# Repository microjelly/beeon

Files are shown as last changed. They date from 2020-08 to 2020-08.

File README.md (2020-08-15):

# beeon

## Overview
The classic device was created several years ago to fill a single need, preventing my work computer from auto locking due to inactivity. *Subverting security policy comes with a responsibility to ensure that you lock your computer (CTRL+ALT+DEL) everytime you walk away!*  

## classic notes
### flash bootloader to board
`avrdude -c USBasp -p attiny85 -U flash:w:beeon-classic-v1-micronucleus-2.04.hex:i -B 10`  
`avrdude -c USBasp -p attiny85 -U lfuse:w:0xe1:m -U hfuse:w:0xdd:m -U efuse:w:0xfe:m`  
### upload new firmware onto board
`micronucleus --run {firmware.hex}`
### clear out any existing firmware
`micronucleus --erase-only`
### upload firmware with random serial number
*first create random serial number file*  
`beeon-classic-sn -mk -mk-p=Z-ZZ > beeon-sn.txt`  
`beeon-classic-sn | micronucleus --run -`

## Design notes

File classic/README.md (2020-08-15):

[finished-product-image]: hw/img/classic-v1.jpg "BEEON - Classic; v1"
[pcb-top-image]: hw/img/classic-v1-top.png "BEEON - Classic; v1; pcb-top"
[pcb-bottom-image]: hw/img/classic-v1-bottom.png "BEEON - Classic; v1; pcb-bottom"

# classic hardware

## Overview
The classic device was created several years ago to fill a single need, preventing my work computer from auto locking due to inactivity. *Subverting security policy comes with a responsibility to ensure that you lock your computer (CTRL+ALT+DEL) everytime you walk away!*  

Alternatively the device can also be used as a low-pin USB development platform, by soldering a pin header to the exposed pads on the bottom you can access 3 GPIOS, VCC (3v3+), GND and the RESET pin of the ATTINY85. Making it a very low-pin count development board with USB capabilities.

---
## Firmware
The firmware makes use of the outstanding V-USB software-only implementation of low-speed USB devices. If you plan on making changes or releasing your own devices please change the vendor/device names as well as the vendor/product ids within the [usbconfig.h](fw/v1/usbconfig.h) file.
    
`V-USB` is released under the [GPLv2](https://github.com/obdev/v-usb/blob/master/usbdrv/License.txt) license.

---
## Bootloader
Micronucleus is the bootloader that is currently in use by the beeon-classic devices. You will need a copy of the commandline tool for your operating system inorder to upload new firmware onto the device. v2.04 is the version that we are currently using.
  
| OS | Link |
| -- | -- |
| Windows | [Download](https://github.com/micronucleus/micronucleus/raw/master/commandline/micronucleus.exe) |
| Linux/Darwin | [Build](https://github.com/micronucleus/micronucleus/tree/master/commandline) |
`Micronucleus` is released under the [GPLv2](https://github.com/micronucleus/micronucleus/blob/master/License.txt) license.

---
## BOM
| Reference(s) | Package  | Description | Manufacturer | Part Number | **Cost |
| --- | ---: | --- | --- | ---: | -----: |
| SW1 | | Switch | E-Switch | *TL1014BF180QG | $#.##  |
| D1 | 1206 | LED | OSRAM Opto | *LG N971-KN-1 | $#.##  |
| J1 | | 6 PIN 2.54mm (Optional Header) | Harwin | M20-7820646 | $0.95  |
| J2 | | USB | CNC-Tech | 1001-011-01101 | $0.77  |
| R1 | 0805 | 47 Ohm Resistor | Vishay/Dale | CRCW080547R0FKEA | $0.10  |
| R2 | 0805 | 1K5 Ohm Resistor | Vishay/Dale | CRCW08051K50FKEB | $0.17  |
| R3 | 0805 | 68 Ohm Resistor | Vishay/Dale | CRCW080568R0FKEA | $0.10  |
| R4 | 0805 | 68 Ohm Resistor | Vishay/Dale | CRCW080568R0FKEA | $0.10  |
| U1 | SOIC-8 | ATtiny85 MCU | Atmel | ATtiny85-20SU | $1.13  |
| U2 | SOT-23-5 | 1 00mA 3.3 LDO | Texas Instruments | TPS79133DBVR | $1.32  |
| C1 | 1206 | 10uF 10v Tantalum Capacitor | AVX | F931A106KAA | $0.49  |
| C2 | 1206 | 0.1uF 10v MLCC Capacitor | Vishay/Vitramon | VJ1206Y104KXQPW1BC | $0.29  |
| C3 | 1206 | 0.01uF 10v MLCC Capacitor | Vishay/Vitramon | VJ1206Y103KXJCW1BC | $0.25  |
| C4 | 1206 | 1uF 16v Tantalum Capacitor | AVX | F931C105KAA | $0.51  |

**obsolete part (need to find replacement)*  
***cost last updated on 8/14/2020*

---
## PCB
[`Order from OSH Park`](https://oshpark.com/shared_projects/amtuUCdw)  
               

---
## Finished Product
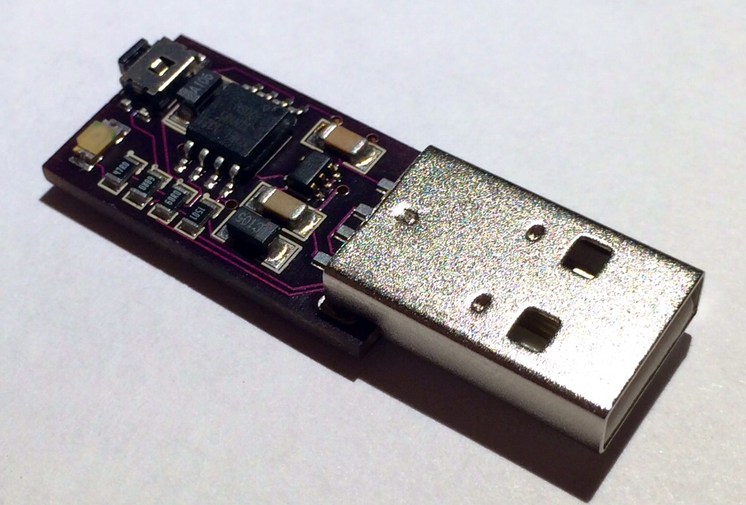
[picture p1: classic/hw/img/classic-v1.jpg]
|  |
| :---------------------------------- |

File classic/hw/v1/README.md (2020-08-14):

[finished-product-image]: classic-v1.jpg "BEEON - Classic; v1"
[pcb-top-image]: classic-v1-top.png "BEEON - Classic; v1; pcb-top"
[pcb-bottom-image]: classic-v1-bottom.png "BEEON - Classic; v1; pcb-bottom"

# classic v1 hardware
## Overview
A brief overview of why have a classic version

## BOM
Some words aboutthe current bom
| Reference(s) | Package  | Description | Manufacturer | Part Number | Cost  |
| --- | --- | --- | --- | --- | ----- |
| SW1 | | Switch | E-Switch | *TL1014BF180QG | $#.## |
| D1 | 1206 | LED | OSRAM Opto | *LG N971-KN-1 | $#.## |
| J1 | | 6 PIN 2.54mm (Optional Header) | Harwin | M20-7820646 | $0.95 |
| J2 | | USB | CNC-Tech | 1001-011-01101 | $0.77 |
| R1 | 0805 | 47 Ohm Resistor | Vishay/Dale | CRCW080547R0FKEA | $0.10 |
| R2 | 0805 | 1K5 Ohm Resistor | Vishay/Dale | CRCW08051K50FKEB | $0.17 |
| R3 | 0805 | 68 Ohm Resistor | Vishay/Dale | CRCW080568R0FKEA | $0.10 |
| R4 | 0805 | 68 Ohm Resistor | Vishay/Dale | CRCW080568R0FKEA | $0.10 |
| U1 | SOIC-8 | ATtiny85 MCU | Atmel | ATtiny85-20SU | $1.13 |
| U2 | SOT-23-5 | 1 00mA 3.3 LDO | Texas Instruments | TPS79133DBVR | $1.32 |
| C1 | 1206 | 10uF 10v Tantalum Capacitor | AVX | F931A106KAA | $0.49 |
| C2 | 1206 | 0.1uF 10v MLCC Capacitor | Vishay/Vitramon | VJ1206Y104KXQPW1BC | $0.29 |
| C3 | 1206 | 0.01uF 10v MLCC Capacitor | Vishay/Vitramon | VJ1206Y103KXJCW1BC | $0.25 |
| C4 | 1206 | 1uF 16v Tantalum Capacitor | AVX | F931C105KAA | $0.51 |

*obsolete part (need to find replacement)

## PCB
Some quick words abou the pcb [`Order from OSH Park`](https://oshpark.com/shared_projects/amtuUCdw)
|   | 
| -------------------------------------------------------- |

## Finished Product
Some quick words about the finished product
|  |
| :---------------------------------- |

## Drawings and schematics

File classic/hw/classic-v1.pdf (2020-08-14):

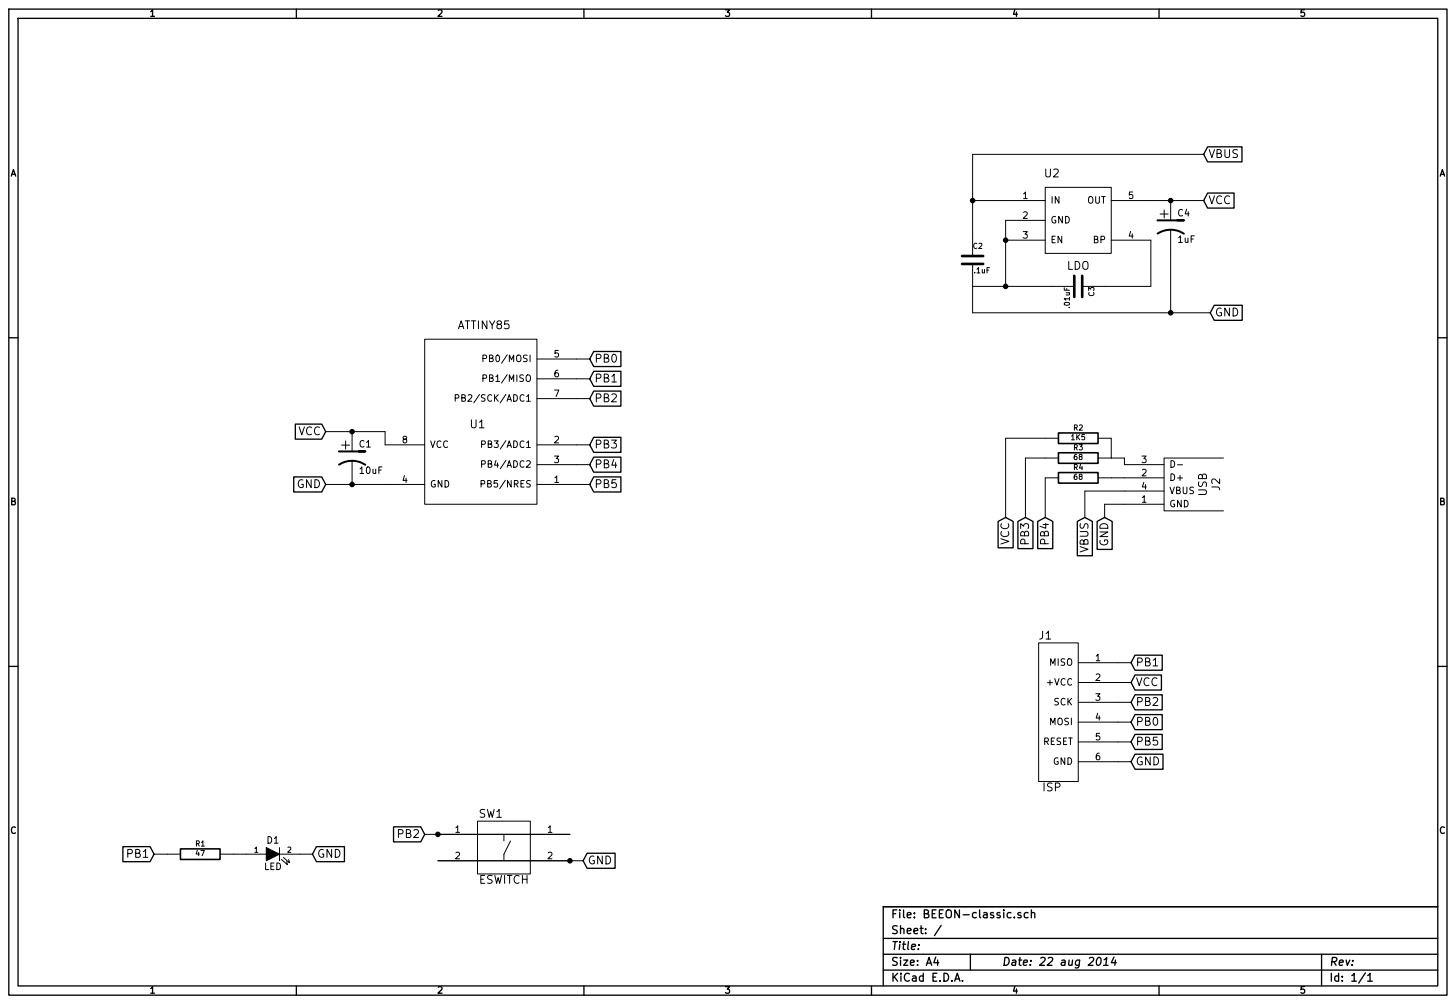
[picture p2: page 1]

Id: 1/1 Title: File: BEEON-classic.sch
Sheet: /

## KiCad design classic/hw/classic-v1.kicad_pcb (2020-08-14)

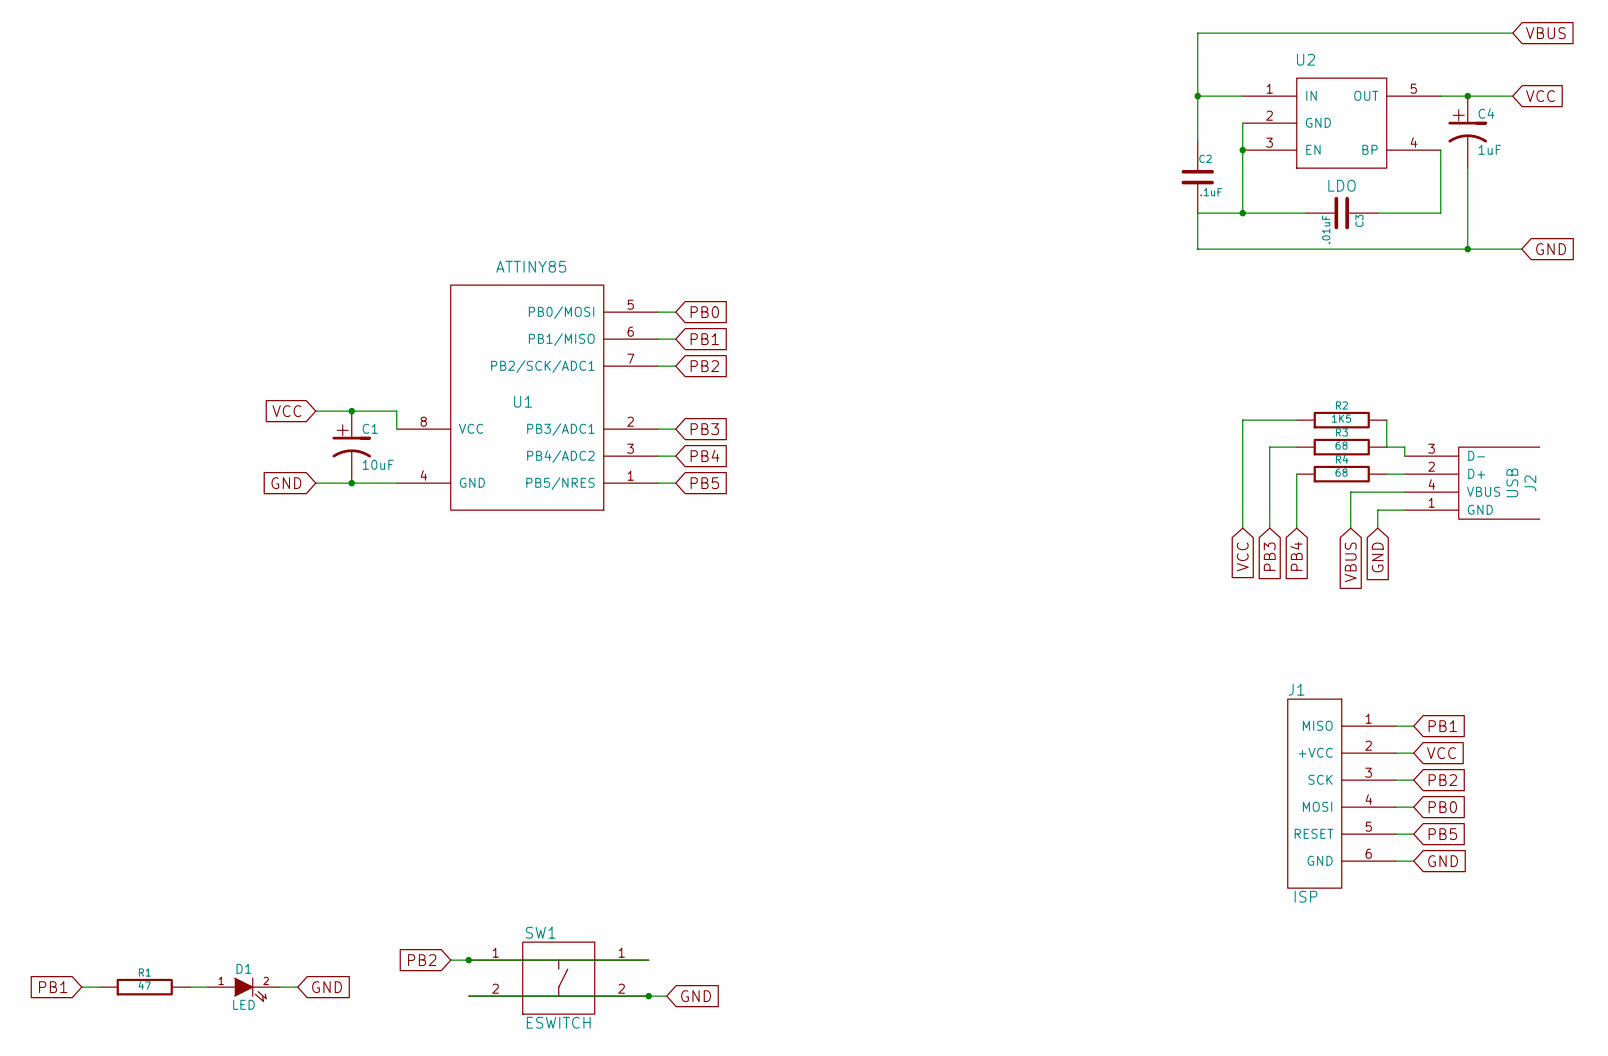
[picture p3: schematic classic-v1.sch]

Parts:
C1: 10uF
C2: .1uF
C3: .01uF
C4: 1uF
D1: LED
J1: ISP
J2: USB
R1: 47
R2: 1K5
R3, R4: 68
SW1: ESWITCH
U1: ATTINY85
U2: LDO

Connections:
GND: C1.2, C2.2, C3.2, C4.2, D1.2 (K), J1.6 (GND), J2.1 (GND), SW1.2, U1.4 (GND), U2.2 (GND), U2.3 (EN)
unnamed: J2.3 (D-), R2.2, R3.2
unnamed: J2.2 (D+), R4.2
unnamed: D1.1 (A), R1.2
unnamed: C3.1, U2.4 (BP)
PB0: J1.4 (MOSI), U1.5 (PB0/MOSI)
PB1: J1.1 (MISO), R1.1, U1.6 (PB1/MISO)
PB2: J1.3 (SCK), SW1.1, U1.7 (PB2/SCK/ADC1)
PB3: R3.1, U1.2 (PB3/ADC1)
PB4: R4.1, U1.3 (PB4/ADC2)
PB5: J1.5 (RESET), U1.1 (PB5/NRES)
VBUS: C2.1, J2.4 (VBUS), U2.1 (IN)
VCC: C1.1, C4.1, J1.2 (+VCC), R2.1, U1.8 (VCC), U2.5 (OUT)

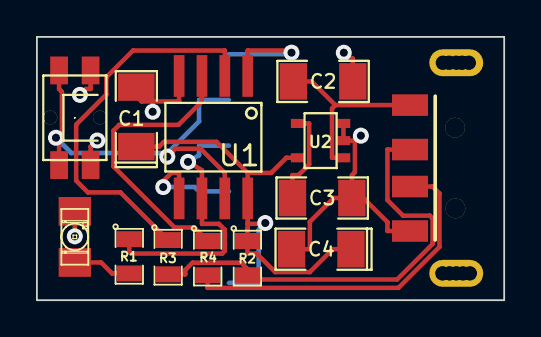
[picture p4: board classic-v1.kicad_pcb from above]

Board: 2 copper layers, 26.0 x 14.6 mm, 14 parts (1 on the bottom side), 13 nets.

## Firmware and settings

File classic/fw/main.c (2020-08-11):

#include <avr/io.h>
#include <avr/wdt.h>
#include <avr/eeprom.h>
#include <avr/interrupt.h>  /* for sei() */
#include <util/delay.h>     /* for _delay_ms() */
#include <stdlib.h>

#include <avr/pgmspace.h>   /* required by usbdrv.h */
#include "usbdrv.h"

#define BIT_KEY 2
#define BIT_LED 1

#define EEPROM_OSC	0
#define EEPROM_DM   1
#define EEPROM_DR	2
#define EEPROM_KK	3
#define EEPROM_MM	4

#define MOUSE_B     1
#define MOUSE_X     2
#define MOUSE_Y     3
#define MOUSE_W	    4

#define DS_IDLE     10
#define DS_ACTIVE   20

#define DR_FAST     1
#define DR_NORMAL   8
#define DR_SLOW     16
#define DR_EXSLOW   32

#define DM_MOUSE    10
#define DM_KEYBOARD 20

#define MM_CIRCLE   10
#define MM_RANDOM   20

#define LED_MAX		9

#define FR_DS		1
#define FR_DM		2
#define FR_DR		3
#define FR_KK		4
#define FR_MM		5

#define KK_0	    0x27
#define KK_CAPS     0x39
#define KK_DEFAULT	KK_0

/* ------------------------------------------------------------------------- */
/* ----------------------------- USB interface ----------------------------- */
/* ------------------------------------------------------------------------- */

PROGMEM const char usbHidReportDescriptor[USB_CFG_HID_REPORT_DESCRIPTOR_LENGTH] = {

// Mouse 
//	-------------------------------------------------------------------------
	0x05, 0x01,//	Usage Page (Generic Desktop),							|
	0x09, 0x02,//	Usage (Mouse),											|
	0xA1, 0x01,//	Collection (Application),								|
	0x09, 0x01,//		Usage (Pointer)										|
	0xA1, 0x00,//		Collection (Physical),								|
//	-------------------------------------------------------------------------
	0x85, 0x01,//			Report Id (1).									|
//	-------------------------------------------------------------------------
	0x05, 0x09,//			Usage Page (Buttons),							|
	0x19, 0x01,//			Usage Minimum (01),								|
	0x29, 0x03,//			Usage Maximun (03),								|
	0x15, 0x00,//			Logical Minimum (0),							|
	0x25, 0x01,//			Logical Maximum (1),							|
	0x95, 0x03,//			Report Count (3),								|
	0x75, 0x01,//			Report Size (1),								|
	0x81, 0x02,//			Input (Data, Var, Abs),							|
	0x95, 0x01,//			Report Count (1),								|
	0x75, 0x05,//			Report Size (5),								|
	0x81, 0x03,//			Input (Constant), ;5 bit padding				|
//	-------------------------------------------------------------------------
	0x05, 0x01,//			Usage Page (Generic Desktop),					|
	0x09, 0x30,//			Usage (X),										|
	0x09, 0x31,//			Usage (Y),										|
	0x09, 0x38,//			Usage (Wheel),									|
	0x15, 0x81,//			Logical Minimum (-127),							|
	0x25, 0x7F,//			Logical Maximum (127),							|
	0x75, 0x08,//			Report Size (8),								|
	0x95, 0x03,//			Report Count (3),								|
	0x81, 0x06,//			Input (Data, Var, Rel)							|
//	-------------------------------------------------------------------------
	0xC0,//				End Collection,										|
//	-------------------------------------------------------------------------
// Configuration interface
//	-------------------------------------------------------------------------
	0x09, 0x00,//	    USAGE (Vendor Usage 1)								|
//	-------------------------------------------------------------------------
	0x85, 0x03,//		Report Id (3)										|
//	-------------------------------------------------------------------------
	0x15, 0x00,//		LOGICAL_MINIMUM (0)									|
	0x26, 0xff, 0x00,//	LOGICAL_MAXIMUM (255)								|
	0x75, 0x08,//		REPORT_SIZE (8)										|
	0x95, 0x05,//		REPORT_COUNT (5)									|
	0xb1, 0x02,//		FEATURE (Data,Var,Abs)								|
	0xC0,//			End Collection											|
//	-------------------------------------------------------------------------

// Keyboard
//	-------------------------------------------------------------------------
	0x05, 0x01,//	USAGE_PAGE (Generic Desktop)							|
	0x09, 0x06,//	USAGE (Keyboard)										|
	0xa1, 0x01,//	COLLECTION (Application)								|
//	-------------------------------------------------------------------------
	0x85, 0x02,//		Report Id (2)										|
//	-------------------------------------------------------------------------
	0x05, 0x07,//		USAGE_PAGE (Keyboard)								|
	0x19, 0xe0,//		USAGE_MINIMUM (Keyboard LeftControl)				|
	0x29, 0xe7,//		USAGE_MAXIMUM (Keyboard Right GUI)					|
	0x15, 0x00,//		LOGICAL_MINIMUM (0)									|
	0x25, 0x01,//		LOGICAL_MAXIMUM (1)									|
	0x75, 0x01,//		REPORT_SIZE (1)										|
	0x95, 0x08,//		REPORT_COUNT (8)									|
	0x81, 0x02,//		INPUT (Data,Var,Abs)								|
//	-------------------------------------------------------------------------
	0x95, 0x05,//		REPORT_COUNT (5)									|
	0x75, 0x01,//		REPORT_SIZE (1)										|
	0x05, 0x08,//		USAGE_PAGE (LEDs)									|
	0x19, 0x01,//		USAGE_MINIMUM (Num Lock)							|
	0x29, 0x05,//		USAGE_MAXIMUM (Kana)								|
	0x91, 0x02,//		OUTPUT (Data,Var,Abs)								|
//	-------------------------------------------------------------------------
	0x95, 0x01,//		REPORT_COUNT (1)									|
	0x75, 0x03,//		REPORT_SIZE (3)										|
	0x91, 0x03,//		OUTPUT (Cnst,Var,Abs)								|
//	-------------------------------------------------------------------------
	0x95, 0x06,//		REPORT_COUNT (6)									|
	0x75, 0x08,//		REPORT_SIZE (8)										|
	0x15, 0x00,//		LOGICAL_MINIMUM (0)									|
	0x25, 0x65,//		LOGICAL_MAXIMUM (101)								|
	0x05, 0x07,//		USAGE_PAGE (Keyboard)								|
	0x19, 0x00,//		USAGE_MINIMUM (Reserved (no event indicated))		|
	0x29, 0x65,//		USAGE_MAXIMUM (Keyboard Application)				|
	0x81, 0x00,//		INPUT (Data,Ary,Abs)								|
//	-------------------------------------------------------------------------
	0xc0,//			END_COLLECTION  										|
//	-------------------------------------------------------------------------
};



static uchar currentAddress;
static uchar bytesRemaining;

static uchar mouseReportBuffer[5]    = { 1, 0,0,0,0 };
static uchar keyboardReportBuffer[8] = { 2, 0,0,0,0,0,0,0 };
static uchar featureReportBuffer[6]  = { 3, 0,0,0,0,0 };

static int   	sinus = 7 << 6, cosinus = 0;
static uchar    idleRate;   /* repeat rate for keyboards, never used for mice */

static uchar 	deviceStatus = DS_IDLE;
static uchar	deviceRate   = DR_NORMAL;
static uchar	deviceMode   = DM_MOUSE;
static uchar	mouseMode    = MM_RANDOM;
static uchar	keyboardKey  = KK_DEFAULT;
static uchar    runToken     = 1; 

static void toggleDeviceStatus()
{
    if(deviceStatus==DS_ACTIVE){

        deviceStatus = DS_IDLE;
        PORTB |= 1 << BIT_LED;      /* LED on */
    }else{
    
        deviceStatus = DS_ACTIVE;
        PORTB &= ~(1 << BIT_LED);   /* LED off */
    }
}


static void keyPoll(void)
{
static uchar    keyMirror;
uchar           key;

    key = PINB & (1 << BIT_KEY);
    if(keyMirror != key){   /* status changed */
        keyMirror = key;
        if(!key) toggleDeviceStatus();
    }
}

static void timerPoll(void)
{
static int timerCnt;
static int timerCnt2;
static int timerLed;

    if(TIFR & (1 << TOV1)){
        TIFR = (1 << TOV1); /* clear overflow */
        keyPoll();
        if(++timerCnt >= deviceRate){
          timerCnt = 0;
          if(++timerCnt2 >= deviceRate){
            timerCnt2 = 0;
            runToken = 1;
          }
        }
        if(++timerLed >= LED_MAX){
            timerLed = 0;
            if(deviceStatus==DS_ACTIVE && (PINB & (1 << BIT_KEY)) ){
              PORTB &= ~(1 << BIT_LED);   /* LED off */
            }
        }
    }
}

/* The following function advances sin/cos by a fixed angle
 * and stores the difference to the previous coordinates in the report
 * descriptor.
 * The algorithm is the simulation of a second order differential equation.
 */
static void advanceCircleByFixedAngle(void)
{
char    d;

#define DIVIDE_BY_64(val)  (val + (val > 0 ? 32 : -32)) >> 6    /* rounding divide */

    mouseReportBuffer[MOUSE_X] = d = DIVIDE_BY_64(cosinus);
    sinus += d;
    mouseReportBuffer[MOUSE_Y] = d = DIVIDE_BY_64(sinus);
    cosinus -= d;
}

static void randomMouse(void)
{

    mouseReportBuffer[MOUSE_X] = ((rand() / (RAND_MAX / 254 + 1))-128)/8;
    mouseReportBuffer[MOUSE_Y] = ((rand() / (RAND_MAX / 254 + 1))-128)/8;
}

/* ------------------------------------------------------------------------- */

/* usbFunctionWrite() is called when the host sends a chunk of data to the
 * device. For more information see the documentation in usbdrv/usbdrv.h.
 */
uchar usbFunctionWrite(uchar *data, uchar len) {

	uchar i;
	
    if(bytesRemaining == 0)
        return 1;               /* end of transfer */
    if(len > bytesRemaining)
        len = bytesRemaining;

	for(i = 0; i < len; i++) {

		if(currentAddress==FR_DS && data[i]!=0xff && data[i]!=deviceStatus) toggleDeviceStatus();
		else if(currentAddress==FR_DM && data[i]!=0xff && data[i]!=deviceMode && (data[i]==DM_MOUSE||data[i]==DM_KEYBOARD) ) {
			eeprom_write_byte(EEPROM_DM, data[i]);
			deviceMode=data[i];
		} else if(currentAddress==FR_DR && data[i]!=0xff && data[i]!=deviceRate) {
			eeprom_write_byte(EEPROM_DR, data[i]);
			deviceRate=data[i];
		} else if(currentAddress==FR_KK && data[i]!=0xff && data[i]!=keyboardKey) {
			eeprom_write_byte(EEPROM_KK, data[i]);
			keyboardKey=data[i];
		} else if(currentAddress==FR_MM && data[i]!=0xff && data[i]!=mouseMode && (data[i]==MM_CIRCLE||data[i]==MM_RANDOM) ) {
			eeprom_write_byte(EEPROM_MM, data[i]);
			mouseMode=data[i];
		}

    	currentAddress++;
    }
      
    currentAddress += len;
    bytesRemaining -= len;
    return bytesRemaining == 0; /* return 1 if this was the last chunk */
}

usbMsgLen_t usbFunctionSetup(uchar data[8])
{
usbRequest_t    *rq = (void *)data;

    /* The following requests are never used. But since they are required by
     * the specification, we implement them in this example.
     */
    if((rq->bmRequestType & USBRQ_TYPE_MASK) == USBRQ_TYPE_CLASS){    /* class request type */
        if(rq->bRequest == USBRQ_HID_GET_REPORT){
            /* wValue: ReportType (highbyte), ReportID (lowbyte) */
            if (rq->wValue.bytes[0] == 1) {
                usbMsgPtr = (void *)&mouseReportBuffer;
                return sizeof(mouseReportBuffer);
            } else if (rq->wValue.bytes[0] == 2) {
                usbMsgPtr = (void *)&keyboardReportBuffer;
                return sizeof(keyboardReportBuffer);
            } else if (rq->wValue.bytes[0] == 3) {
            	featureReportBuffer[FR_DS] = deviceStatus;
            	featureReportBuffer[FR_DM] = deviceMode;
            	featureReportBuffer[FR_DR] = deviceRate;
            	featureReportBuffer[FR_KK] = keyboardKey;
            	featureReportBuffer[FR_MM] = mouseMode;
                usbMsgPtr = (void *)&featureReportBuffer;
                return sizeof(featureReportBuffer);
            }
            return 0;
        } else if(rq->bRequest == USBRQ_HID_SET_REPORT){
        	if (rq->wValue.bytes[0] == 3) {
            	bytesRemaining = rq->wLength.word;
            	currentAddress = 0;
            	return USB_NO_MSG;
            }
        } else if(rq->bRequest == USBRQ_HID_GET_IDLE){
            usbMsgPtr = &idleRate;
            return 1;
        }else if(rq->bRequest == USBRQ_HID_SET_IDLE){
            idleRate = rq->wValue.bytes[1];
        }
    }else{
        /* no vendor specific requests implemented */
    }
    return 0;   /* default for not implemented requests: return no data back to host */
}

/* ------------------------------------------------------------------------- */

/* ------------------------------------------------------------------------- */
/* ------------------------ Oscillator Calibration ------------------------- */
/* ------------------------------------------------------------------------- */

/* Calibrate the RC oscillator to 8.25 MHz. The core clock of 16.5 MHz is
 * derived from the 66 MHz peripheral clock by dividing. Our timing reference
 * is the Start Of Frame signal (a single SE0 bit) available immediately after
 * a USB RESET. We first do a binary search for the OSCCAL value and then
 * optimize this value with a neighboorhod search.
 * This algorithm may also be used to calibrate the RC oscillator directly to
 * 12 MHz (no PLL involved, can therefore be used on almost ALL AVRs), but this
 * is wide outside the spec for the OSCCAL value and the required precision for
 * the 12 MHz clock! Use the RC oscillator calibrated to 12 MHz for
 * experimental purposes only!
 */
static void calibrateOscillator(void)
{
uchar       step = 128;
uchar       trialValue = 0, optimumValue;
int         x, optimumDev, targetValue = (unsigned)(1499 * (double)F_CPU / 10.5e6 + 0.5);

    /* do a binary search: */
    do{
        OSCCAL = trialValue + step;
        x = usbMeasureFrameLength();    /* proportional to current real frequency */
        if(x < targetValue)             /* frequency still too low */
            trialValue += step;
        step >>= 1;
    }while(step > 0);
    /* We have a precision of +/- 1 for optimum OSCCAL here */
    /* now do a neighborhood search for optimum value */
    optimumValue = trialValue;
    optimumDev = x; /* this is certainly far away from optimum */
    for(OSCCAL = trialValue - 1; OSCCAL <= trialValue + 1; OSCCAL++){
        x = usbMeasureFrameLength() - targetValue;
        if(x < 0)
            x = -x;
        if(x < optimumDev){
            optimumDev = x;
            optimumValue = OSCCAL;
        }
    }
    OSCCAL = optimumValue;
}
/*
Note: This calibration algorithm may try OSCCAL values of up to 192 even if
the optimum value is far below 192. It may therefore exceed the allowed clock
frequency of the CPU in low voltage designs!
You may replace this search algorithm with any other algorithm you like if
you have additional constraints such as a maximum CPU clock.
For version 5.x RC oscillators (those with a split range of 2x128 steps, e.g.
ATTiny25, ATTiny45, ATTiny85), it may be useful to search for the optimum in
both regions.
*/

void    hadUsbReset(void)
{
    calibrateOscillator();
    eeprom_write_byte(EEPROM_OSC, OSCCAL);   /* store the calibrated value in EEPROM */
}

static void timerInit(void)
{
    TCCR1 = 0x0b;           /* select clock: 16.5M/1k -> overflow rate = 16.5M/256k = 62.94 Hz */
}

int __attribute__((noreturn)) main(void)
{
uchar   i;
uchar   calibrationValue;

    PORTB |= 1 << BIT_KEY;  /* pull-up on key input */
    DDRB |= 1 << BIT_LED;   /* output for LED */
    
    calibrationValue = eeprom_read_byte(EEPROM_OSC); /* calibration value from last time */
    if(calibrationValue != 0xff){
        OSCCAL = calibrationValue;
    }

    i = eeprom_read_byte(EEPROM_DM);
    if(i != 0xff) deviceMode = i;
    
    i = eeprom_read_byte(EEPROM_DR);
    if(i != 0xff) deviceRate = i;
    else deviceRate = DR_EXSLOW;
    
    i = eeprom_read_byte(EEPROM_KK);
    if(i != 0xff) keyboardKey = i;
    
    i = eeprom_read_byte(EEPROM_MM);
    if(i != 0xff) mouseMode = i;
    
    usbInit();
    usbDeviceDisconnect();  /* enforce re-enumeration, do this while interrupts are disabled! */
    for(i=0;i<20;i++){ /* 300 ms disconnect */
        _delay_ms(15);
    }
    usbDeviceConnect();

    wdt_enable(WDTO_1S);

    timerInit();
    usbInit();
    sei();

    PORTB |= 1 << BIT_LED;      /* LED on */

    for(;;){                /* main event loop */
        wdt_reset();
        usbPoll();
        if(usbInterruptIsReady() && keyboardReportBuffer[2]!=0) {
        
                keyboardReportBuffer[2] = 0;
                usbSetInterrupt((void *)&keyboardReportBuffer, sizeof(keyboardReportBuffer));
        } else if(usbInterruptIsReady() && (deviceStatus==DS_ACTIVE) && runToken){

	    	if(deviceMode==DM_MOUSE) {
		    
	        	if(mouseMode==MM_CIRCLE) advanceCircleByFixedAngle();
	        	else randomMouse();
                PORTB |= 1 << BIT_LED;      /* LED on */
               	usbSetInterrupt((void *)&mouseReportBuffer, sizeof(mouseReportBuffer));
           	} else {

               	keyboardReportBuffer[2] = keyboardKey;
               	usbSetInterrupt((void *)&keyboardReportBuffer, sizeof(keyboardReportBuffer));
           	}
           	runToken = 0;
        }
        timerPoll();
    }
}

/* ------------------------------------------------------------------------- */

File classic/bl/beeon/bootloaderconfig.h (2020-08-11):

/* Name: bootloaderconfig.h
 * Micronucleus configuration file. 
 * This file (together with some settings in Makefile.inc) configures the boot loader
 * according to the hardware.
 * 
 * Controller type: ATtiny 85 - 16.5 MHz
 * Configuration:   Default configuration
 *       USB D- :   PB3
 *       USB D+ :   PB4
 *       Entry  :   Always
 *       LED    :   None
 *       OSCCAL :   Stays at 16 MHz
 * Note: Uses 16.5 MHz V-USB implementation with PLL
 * Last Change:     Mar 16,2014
 *
 * License: GNU GPL v2 (see License.txt
 */
#ifndef __bootloaderconfig_h_included__
#define __bootloaderconfig_h_included__

/* ------------------------------------------------------------------------- */
/*                       Hardware configuration.                             */
/*      Change this according to your CPU and USB configuration              */
/* ------------------------------------------------------------------------- */

#define USB_CFG_IOPORTNAME      B
  /* This is the port where the USB bus is connected. When you configure it to
   * "B", the registers PORTB, PINB and DDRB will be used.
   */

#define USB_CFG_DMINUS_BIT      3
/* This is the bit number in USB_CFG_IOPORT where the USB D- line is connected.
 * This may be any bit in the port.
 */
#define USB_CFG_DPLUS_BIT       4
/* This is the bit number in USB_CFG_IOPORT where the USB D+ line is connected.
 * This may be any bit in the port, but must be configured as a pin change interrupt.
 */

#define USB_CFG_CLOCK_KHZ       (F_CPU/1000)
/* Clock rate of the AVR in kHz. Legal values are 12000, 12800, 15000, 16000,
 * 16500, 18000 and 20000. The 12.8 MHz and 16.5 MHz versions of the code
 * require no crystal, they tolerate +/- 1% deviation from the nominal
 * frequency. All other rates require a precision of 2000 ppm and thus a
 * crystal!
 * Since F_CPU should be defined to your actual clock rate anyway, you should
 * not need to modify this setting.
 */

/* ------------- Set up interrupt configuration (CPU specific) --------------   */
/* The register names change quite a bit in the ATtiny family. Pay attention    */
/* to the manual. Note that the interrupt flag system is still used even though */
/* interrupts are disabled. So this has to be configured correctly.             */


// setup interrupt for Pin Change for D+
#define USB_INTR_CFG            PCMSK
#define USB_INTR_CFG_SET        (1 << USB_CFG_DPLUS_BIT)
#define USB_INTR_CFG_CLR        0
#define USB_INTR_ENABLE         GIMSK
#define USB_INTR_ENABLE_BIT     PCIE
#define USB_INTR_PENDING        GIFR
#define USB_INTR_PENDING_BIT    PCIF
#define USB_INTR_VECTOR         PCINT0_vect

/* ------------------------------------------------------------------------- */
/*       Configuration relevant to the CPU the bootloader is running on      */
/* ------------------------------------------------------------------------- */

// how many milliseconds should host wait till it sends another erase or write?
// needs to be above 4.5 (and a whole integer) as avr freezes for 4.5ms
#define MICRONUCLEUS_WRITE_SLEEP 5


/* ---------------------- feature / code size options ---------------------- */
/*               Configure the behavior of the bootloader here               */
/* ------------------------------------------------------------------------- */

/*
 *  Define Bootloader entry condition
 * 
 *  If the entry condition is not met, the bootloader will not be activated and the user program
 *  is executed directly after a reset. If no user program has been loaded, the bootloader
 *  is always active.
 * 
 *  ENTRY_ALWAYS        Always activate the bootloader after reset. Requires the least
 *                      amount of code.
 *
 *  ENTRY_WATCHDOG      Activate the bootloader after a watchdog reset. This can be used
 *                      to enter the bootloader from the user program.
 *                      Adds 22 bytes.
 *
 *  ENTRY_EXT_RESET     Activate the bootloader after an external reset was issued by 
 *                      pulling the reset pin low. It may be necessary to add an external
 *                      pull-up resistor to the reset pin if this entry method appears to
 *                      behave unreliably.
 *                      Adds 22 bytes.
 *
 *  ENTRY_JUMPER        Activate the bootloader when a specific pin is pulled low by an 
 *                      external jumper. 
 *                      Adds 34 bytes.
 *
 *       JUMPER_PIN     Pin the jumper is connected to. (e.g. PB0)
 *       JUMPER_PORT    Port out register for the jumper (e.g. PORTB)  
 *       JUMPER_DDR     Port data direction register for the jumper (e.g. DDRB)  
 *       JUMPER_INP     Port inout register for the jumper (e.g. PINB)  
 * 
 */

#define ENTRYMODE ENTRY_JUMPER

#define JUMPER_PIN    PB2
#define JUMPER_PORT   PORTB 
#define JUMPER_DDR    DDRB 
#define JUMPER_INP    PINB 
 
/*
  Internal implementation, don't change this unless you want to add an entrymode.
*/
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

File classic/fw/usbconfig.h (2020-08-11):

/* Name: usbconfig.h
 * Project: V-USB, virtual USB port for Atmel's(r) AVR(r) microcontrollers
 * Author: Christian Starkjohann
 * Creation Date: 2005-04-01
 * Tabsize: 4
 * Copyright: (c) 2005 by OBJECTIVE DEVELOPMENT Software GmbH
 * License: GNU GPL v2 (see License.txt), GNU GPL v3 or proprietary (CommercialLicense.txt)
 */

#ifndef __usbconfig_h_included__
#define __usbconfig_h_included__

/*
General Description:
This file is an example configuration (with inline documentation) for the USB
driver. It configures V-USB for USB D+ connected to Port D bit 2 (which is
also hardware interrupt 0 on many devices) and USB D- to Port D bit 4. You may
wire the lines to any other port, as long as D+ is also wired to INT0 (or any
other hardware interrupt, as long as it is the highest level interrupt, see
section at the end of this file).
*/

/* ---------------------------- Hardware Config ---------------------------- */

#define USB_CFG_IOPORTNAME      B
/* This is the port where the USB bus is connected. When you configure it to
 * "B", the registers PORTB, PINB and DDRB will be used.
 */
#define USB_CFG_DMINUS_BIT      3
/* This is the bit number in USB_CFG_IOPORT where the USB D- line is connected.
 * This may be any bit in the port.
 */
#define USB_CFG_DPLUS_BIT       4
/* This is the bit number in USB_CFG_IOPORT where the USB D+ line is connected.
 * This may be any bit in the port. Please note that D+ must also be connected
 * to interrupt pin INT0! [You can also use other interrupts, see section
 * "Optional MCU Description" below, or you can connect D- to the interrupt, as
 * it is required if you use the USB_COUNT_SOF feature. If you use D- for the
 * interrupt, the USB interrupt will also be triggered at Start-Of-Frame
 * markers every millisecond.]
 */
#define USB_CFG_CLOCK_KHZ       (F_CPU/1000)
/* Clock rate of the AVR in kHz. Legal values are 12000, 12800, 15000, 16000,
 * 16500, 18000 and 20000. The 12.8 MHz and 16.5 MHz versions of the code
 * require no crystal, they tolerate +/- 1% deviation from the nominal
 * frequency. All other rates require a precision of 2000 ppm and thus a
 * crystal!
 * Since F_CPU should be defined to your actual clock rate anyway, you should
 * not need to modify this setting.
 */
#define USB_CFG_CHECK_CRC       0
/* Define this to 1 if you want that the driver checks integrity of incoming
 * data packets (CRC checks). CRC checks cost quite a bit of code size and are
 * currently only available for 18 MHz crystal clock. You must choose
 * USB_CFG_CLOCK_KHZ = 18000 if you enable this option.
 */

/* ----------------------- Optional Hardware Config ------------------------ */

/* #define USB_CFG_PULLUP_IOPORTNAME   D */
/* If you connect the 1.5k pullup resistor from D- to a port pin instead of
 * V+, you can connect and disconnect the device from firmware by calling
 * the macros usbDeviceConnect() and usbDeviceDisconnect() (see usbdrv.h).
 * This constant defines the port on which the pullup resistor is connected.
 */
/* #define USB_CFG_PULLUP_BIT          4 */
/* This constant defines the bit number in USB_CFG_PULLUP_IOPORT (defined
 * above) where the 1.5k pullup resistor is connected. See description
 * above for details.
 */

/* --------------------------- Functional Range ---------------------------- */
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
